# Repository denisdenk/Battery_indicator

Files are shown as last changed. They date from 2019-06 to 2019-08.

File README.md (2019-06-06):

Индикатор заряда батареи + плавный пуск (подключение)
-------------
> **Note:**

> - Индикация заряда 6S литиевой батареи для квадрокоптера посредством 5 лампочек (4 зеленые, одна красная) - 100, 80, 60, 40 и 20%
> - Включение посредством подачи сигнала на затворы двух IRLZ44(или 3705) (нагрузка до 400А)
> - Защита от случайного включения батареи посредством комбинации нажатий на клавишу : **длинное + короткое**, для включения и для отключения цепи батареи и нагрузки.

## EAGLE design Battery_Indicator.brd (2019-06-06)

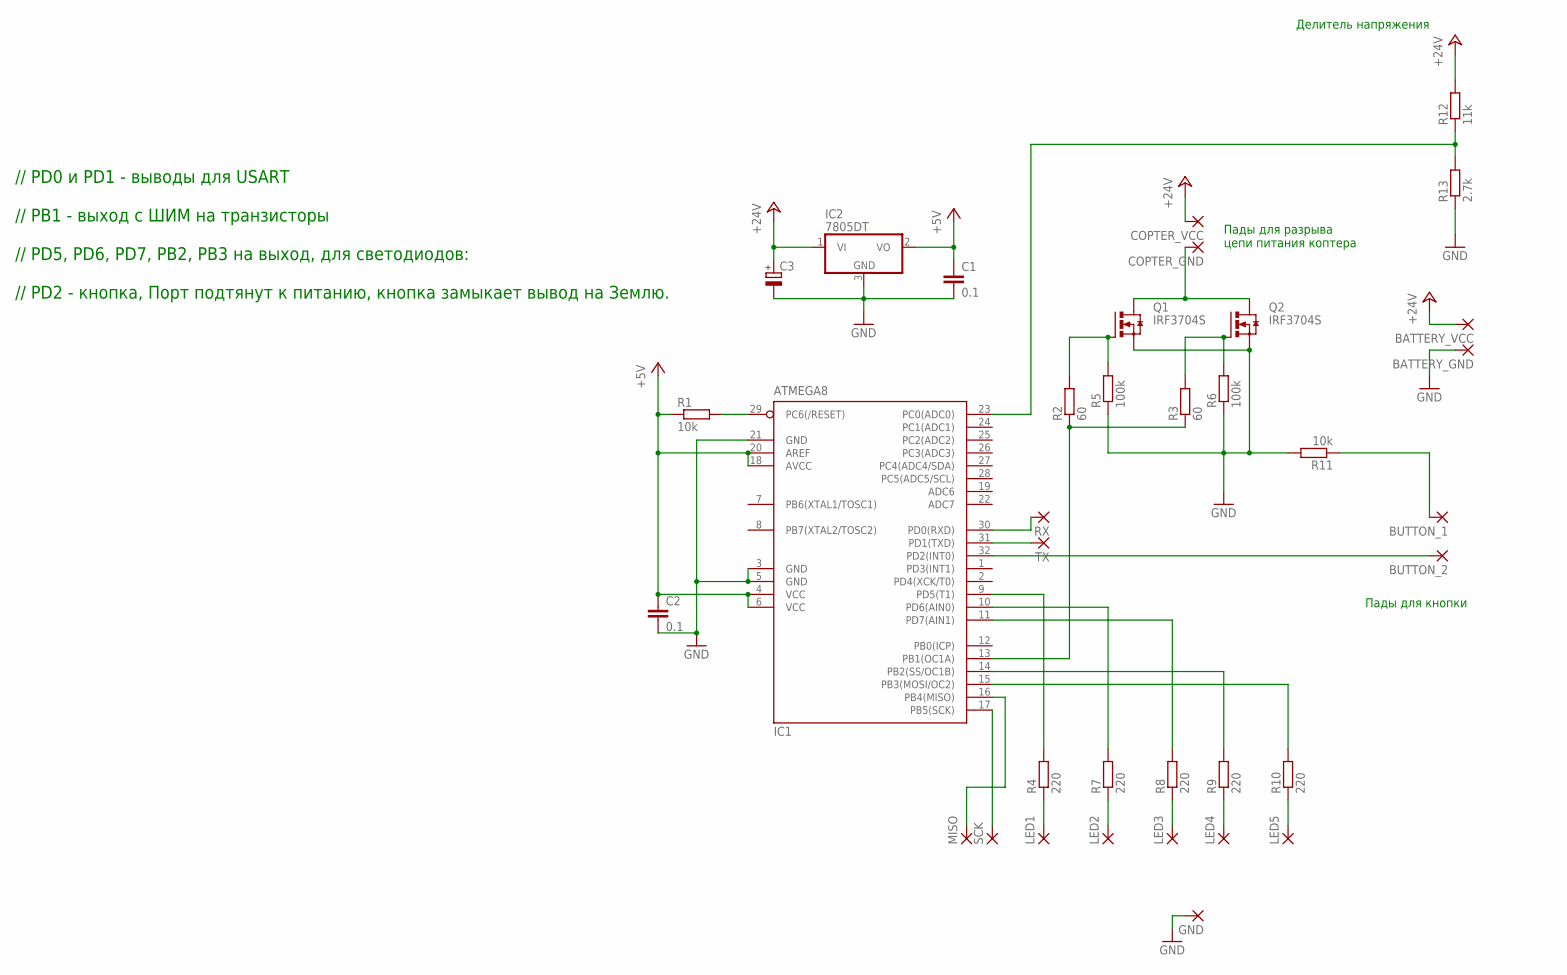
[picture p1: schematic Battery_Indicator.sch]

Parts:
BATTERY_GND: 3,81/1,4
BATTERY_VCC: 3,81/1,4
BUTTON_1, BUTTON_2: SMD2; SMD1,27-2,54
C1, C2: 0.1; C0805
C3: CPOL-EUSMCD; SMC_D
COPTER_GND: 3,81/1,4
COPTER_VCC: 3,81/1,4
GND: SMD2; SMD1,27-2,54
IC1: ATMEGA8; TQFP32-08
IC2: 7805DT; TO252
LED1, LED2, LED3, LED4, LED5: SMD2; SMD1,27-2,54
MISO: SMD2; SMD1,27-2,54
Q1, Q2: IRF3704S; D2PACK
R1, R11: 10k; R0805
R2, R3: 60; R0805
R4, R7, R8, R9, R10: 220; R0805
R5, R6: 100k; R0805
R12: 11k; R0805
R13: 2.7k; R0805
RX: SMD2; SMD1,27-2,54
SCK: SMD2; SMD1,27-2,54
TX: SMD2; SMD1,27-2,54

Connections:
+5V: C1.1, C2.1, IC1.4 (VCC), IC1.6 (VCC), IC1.18 (AVCC), IC1.20 (AREF), IC2.2 (VO), R1.1
+24V: BATTERY_VCC.1, C3.+, COPTER_VCC.1, IC2.1 (VI), R12.2
GND: BATTERY_GND.1, C1.2, C2.2, C3.-, GND.1, IC1.3 (GND), IC1.5 (GND), IC1.21 (GND), IC2.3 (GND), Q1.3 (S), Q2.3 (S), R5.1, R6.1, R11.2, R13.1
unnamed: IC1.9 (PD5(T1)), R4.2
unnamed: Q1.1 (G), R2.2, R5.2
unnamed: IC1.29 (PC6(/RESET)), R1.2
unnamed: Q2.1 (G), R3.2, R6.2
unnamed: COPTER_GND.1, Q1.2 (D), Q2.2 (D)
unnamed: IC1.13 (PB1(OC1A)), R2.1, R3.1
unnamed: LED1.1, R4.1
unnamed: LED2.1, R7.1
unnamed: LED3.1, R8.1
unnamed: LED4.1, R9.1
unnamed: LED5.1, R10.1
unnamed: BUTTON_1.1, R11.1
unnamed: IC1.10 (PD6(AIN0)), R7.2
unnamed: IC1.11 (PD7(AIN1)), R8.2
unnamed: IC1.14 (PB2(SS/OC1B)), R9.2
unnamed: IC1.15 (PB3(MOSI/OC2)), R10.2
unnamed: IC1.30 (PD0(RXD)), RX.1
unnamed: BUTTON_2.1, IC1.32 (PD2(INT0))
unnamed: IC1.23 (PC0(ADC0)), R12.1, R13.2
unnamed: IC1.31 (PD1(TXD)), TX.1
unnamed: IC1.16 (PB4(MISO)), MISO.1
unnamed: IC1.17 (PB5(SCK)), SCK.1

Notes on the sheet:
// PD0 и PD1 - выводы для USART // PB1 - выход с ШИМ на транзисторы // PD5, PD6, PD7, PB2, PB3 на выход, для светодиодов: // PD2 - кнопка, Порт подтянут к питанию, кнопка замыкает вывод на Землю.
Делитель напряжения
Пады для кнопки
Пады для разрыва цепи питания коптера

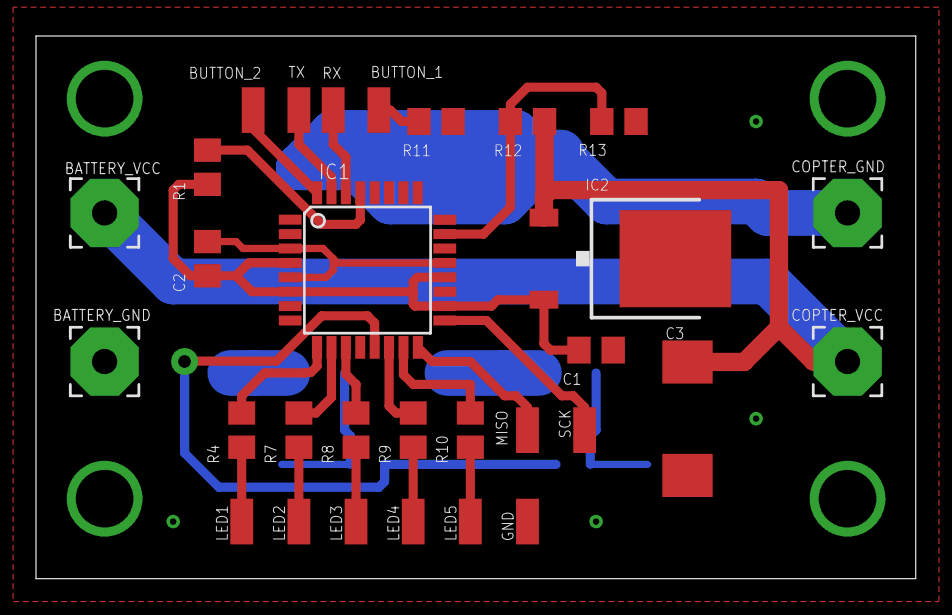
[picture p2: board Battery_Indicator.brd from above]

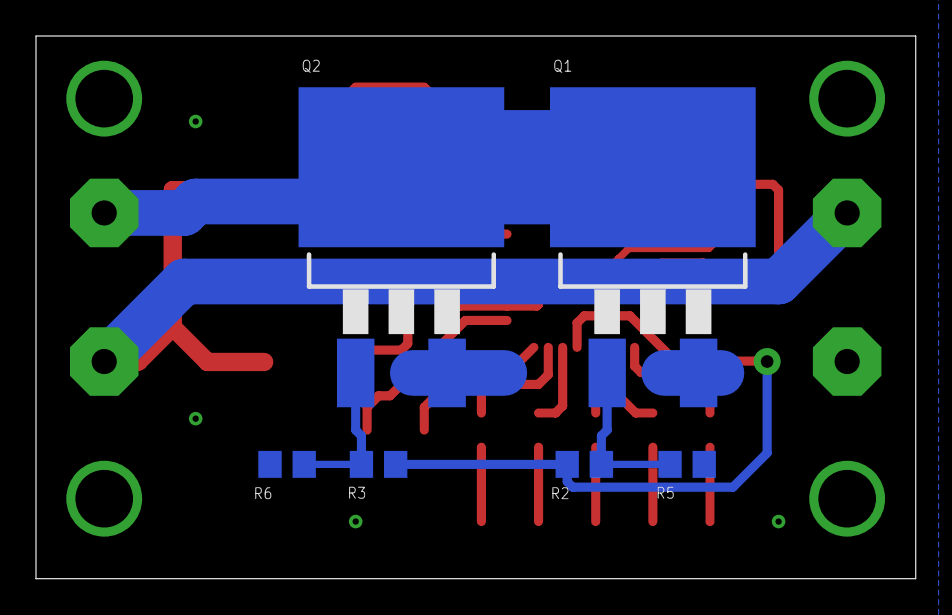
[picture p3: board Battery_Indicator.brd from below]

Board: 2 copper layers, 48.9 x 30.1 mm, 36 parts (6 on the bottom side), 25 nets.

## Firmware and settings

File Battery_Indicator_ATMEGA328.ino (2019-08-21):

/*
 * FUSES: HIGH 0xDE; LOW 0xFF (16MHz External Crystal FOR atmega 8)
 */


uint16_t counter = 0;
int timer = 0;
int i = 0;

bool longPush = false;
bool run = false;

// Function prototypes
void ShowVoltage(void);
float mapping(float x, float in_min, float in_max, float out_min, float out_max);

void setup() {
  Serial.begin(115200);
  // LED`s
  pinMode(5, OUTPUT);
  pinMode(6, OUTPUT);
  pinMode(7, OUTPUT);
  pinMode(10, OUTPUT);
  pinMode(11, OUTPUT);
  // POWER
  pinMode(9, OUTPUT);
  // Button
  pinMode(2, INPUT_PULLUP);

  for (uint8_t i = 0; i < 4; i++) {
    digitalWrite(5, !digitalRead(5));
    digitalWrite(6, !digitalRead(6));
    digitalWrite(7, !digitalRead(7));
    digitalWrite(10, !digitalRead(10));
    digitalWrite(11, !digitalRead(11));
    delay(100);
  }

  analogReference(EXTERNAL);
  analogRead(A0);
  Serial.println("Init OK!");
}

void loop() {
  while (!digitalRead(PD2)) {
    delay(5);
    counter++;
    //Serial.println(counter);
  }
  
  // Если длительное нажатие
  if (counter > 50) {
    // Кнопка была долго нажата, выставляем флаг
    longPush = true;
    counter = 0;
    Serial.println("Long push!\r\n");
  }
  // Если короткое нажатие
  if (counter > 7 && counter < 40) {
    Serial.println("Short push!");
    // Если перед ним было длинное - подключаем/отключаем питание
    if (longPush) {
      // Если работало - отключаем и наоборот
      if (!run) {
        run = true;
        digitalWrite(9, HIGH);
        Serial.println("*******");
        Serial.println("*Work!*");
        Serial.println("*******");
      }
      else {
        digitalWrite(9, LOW);
        run = false;
        Serial.println("************");
        Serial.println("*Work done!*");
        Serial.println("************");
      }
      // Сбрасываем флаг длинного нажатия
      longPush = false;
    }
    // Однократное, короткое нажатие, показываем напряжение
    else {
      counter = 0;
      ShowVoltage();
    }
  }
}

void ShowVoltage(void) {
  /* Получение данных с АЦП */
  int ADCdata[5] = {0};
  int ADC_ExpVal = 0;
  // Считаем напряжение 4 раза и считаем среднее для точности
  for (uint8_t i = 0; i < 4; i++) {
    // Считываем  ADC
    ADCdata[i] = analogRead(A0);
  }

  ADC_ExpVal = (ADCdata[0] + ADCdata[1] + ADCdata[2] + ADCdata[3]) / 4;
  // Опорное напряжение 5В, значение регистра до 1024 => коэффициент = 5/1024=0.0048828
  float voltage = ADC_ExpVal * 0.0048828;
  // Приводим к виду 25.2V.
  voltage = mapping(voltage, 0, 5, 0, 25.2);
  Serial.print("Voltage = ");
  Serial.println(voltage);
  Serial.println();

  /* 100% заряженный аккумулятор = 25,2В.
    0% = 19,8В.
    Разница 5,4В. => 20% это 1.08В.
  */

  // 100%
  if (voltage >= 24.12) {
    PORTD |= (1 << PD5) | (1 << PD6) | (1 << PD7);
    PORTB |= (1 << PB2) | (1 << PB3);

    _delay_ms(500);
    PORTB &= ~(1 << PB2);
    PORTB &= ~(1 << PB3);
    PORTD &= ~(1 << PD5);
    PORTD &= ~(1 << PD6);
    PORTD &= ~(1 << PD7);
  }
  // 80%
  else if (voltage >= 23.04 && voltage < 24.12) {
    PORTD |= (1 << PD5) | (1 << PD6) | (1 << PD7);
    PORTB |= (1 << PB2);
    PORTB &= ~(1 << PB3);

    _delay_ms(500);
    PORTB &= ~(1 << PB2);
    PORTB &= ~(1 << PB3);
    PORTD &= ~(1 << PD5);
    PORTD &= ~(1 << PD6);
    PORTD &= ~(1 << PD7);
  }
  // 60%
  else if (voltage >= 21.96 && voltage < 23.04) {
    PORTD |= (1 << PD5) | (1 << PD6) | (1 << PD7);
    PORTB &= ~(1 << PB2);
    PORTB &= ~(1 << PB3);

    _delay_ms(500);
    PORTB &= ~(1 << PB2);
    PORTB &= ~(1 << PB3);
    PORTD &= ~(1 << PD5);
    PORTD &= ~(1 << PD6);
    PORTD &= ~(1 << PD7);
  }
  // 40%
  else if (voltage >= 20.88 && voltage < 21.96) {
    PORTD |= (1 << PD5) | (1 << PD6);
    PORTD &= ~(1 << PD7);
    PORTB &= ~(1 << PB2);
    PORTB &= ~(1 << PB3);

    _delay_ms(500);
    PORTB &= ~(1 << PB2);
    PORTB &= ~(1 << PB3);
    PORTD &= ~(1 << PD5);
    PORTD &= ~(1 << PD6);
    PORTD &= ~(1 << PD7);
  }
  // 20%
  else if (voltage >= 19.8 && voltage < 20.88) {
    PORTD |= (1 << PD5);
    PORTD &= ~(1 << PD6);
    PORTD &= ~(1 << PD7);
    PORTB &= ~(1 << PB2);
    PORTB &= ~(1 << PB3);

    _delay_ms(500);
    PORTB &= ~(1 << PB2);
    PORTB &= ~(1 << PB3);
    PORTD &= ~(1 << PD5);
    PORTD &= ~(1 << PD6);
    PORTD &= ~(1 << PD7);
  }
}

float mapping(float x, float in_min, float in_max, float out_min, float out_max) {
  return (x - in_min) * (out_max - out_min) / (in_max - in_min) + out_min;
}

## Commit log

2019-01-29 Add project files
    [Battery_Indicator.brd, Battery_Indicator.sch]
2019-06-06 Update EAGLE project files
    [Battery_Indicator.brd, Battery_Indicator.sch]
2019-08-20 Add Arduino project file
